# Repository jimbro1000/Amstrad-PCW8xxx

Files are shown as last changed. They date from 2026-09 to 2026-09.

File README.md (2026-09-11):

# Amstrad PCW8xxx Schematics #
This repository contains a KiCad project representing
the schematics of the main board of the Amstrad
PCW8256 and PCW8512 personal computers

The project is complete for schematics only

The PCB design holds accurate board dimensions and
mostly accurate component positions. Where a component
is a critical reference location this has been 
measured and placed as accurately as possible.

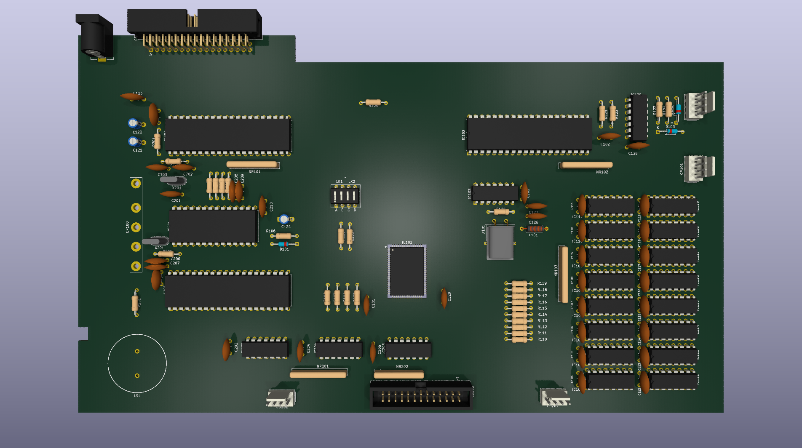
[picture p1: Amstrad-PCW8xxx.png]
render of PCB


# License #
This project is licensed under Creative Commons 4 BY-SA
See LICENSE file for full statement

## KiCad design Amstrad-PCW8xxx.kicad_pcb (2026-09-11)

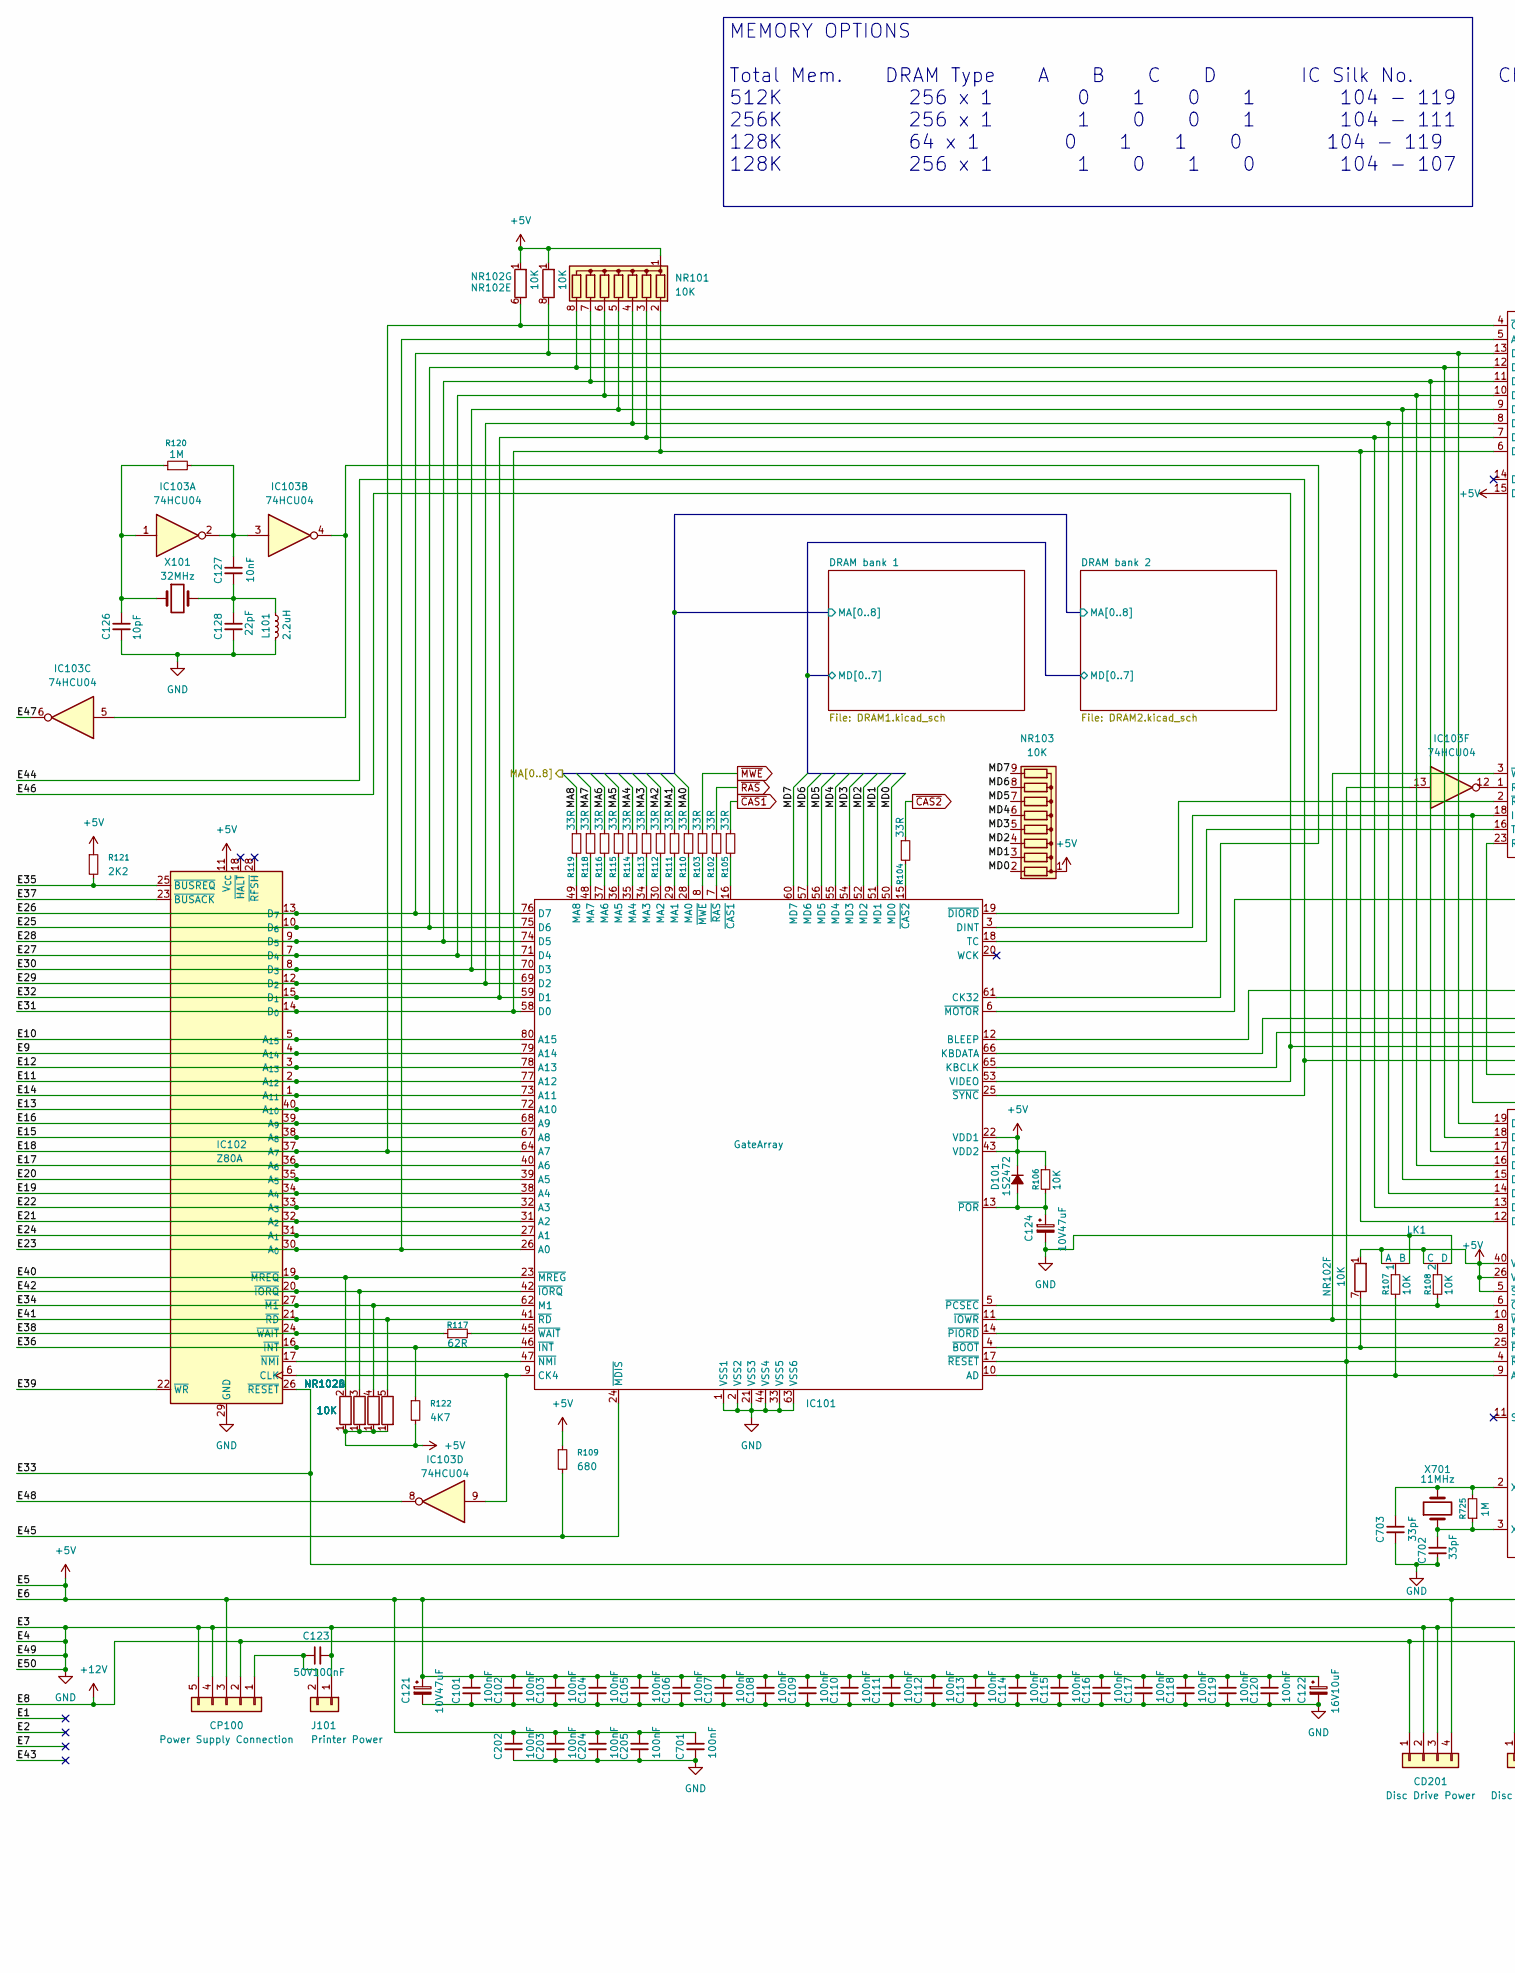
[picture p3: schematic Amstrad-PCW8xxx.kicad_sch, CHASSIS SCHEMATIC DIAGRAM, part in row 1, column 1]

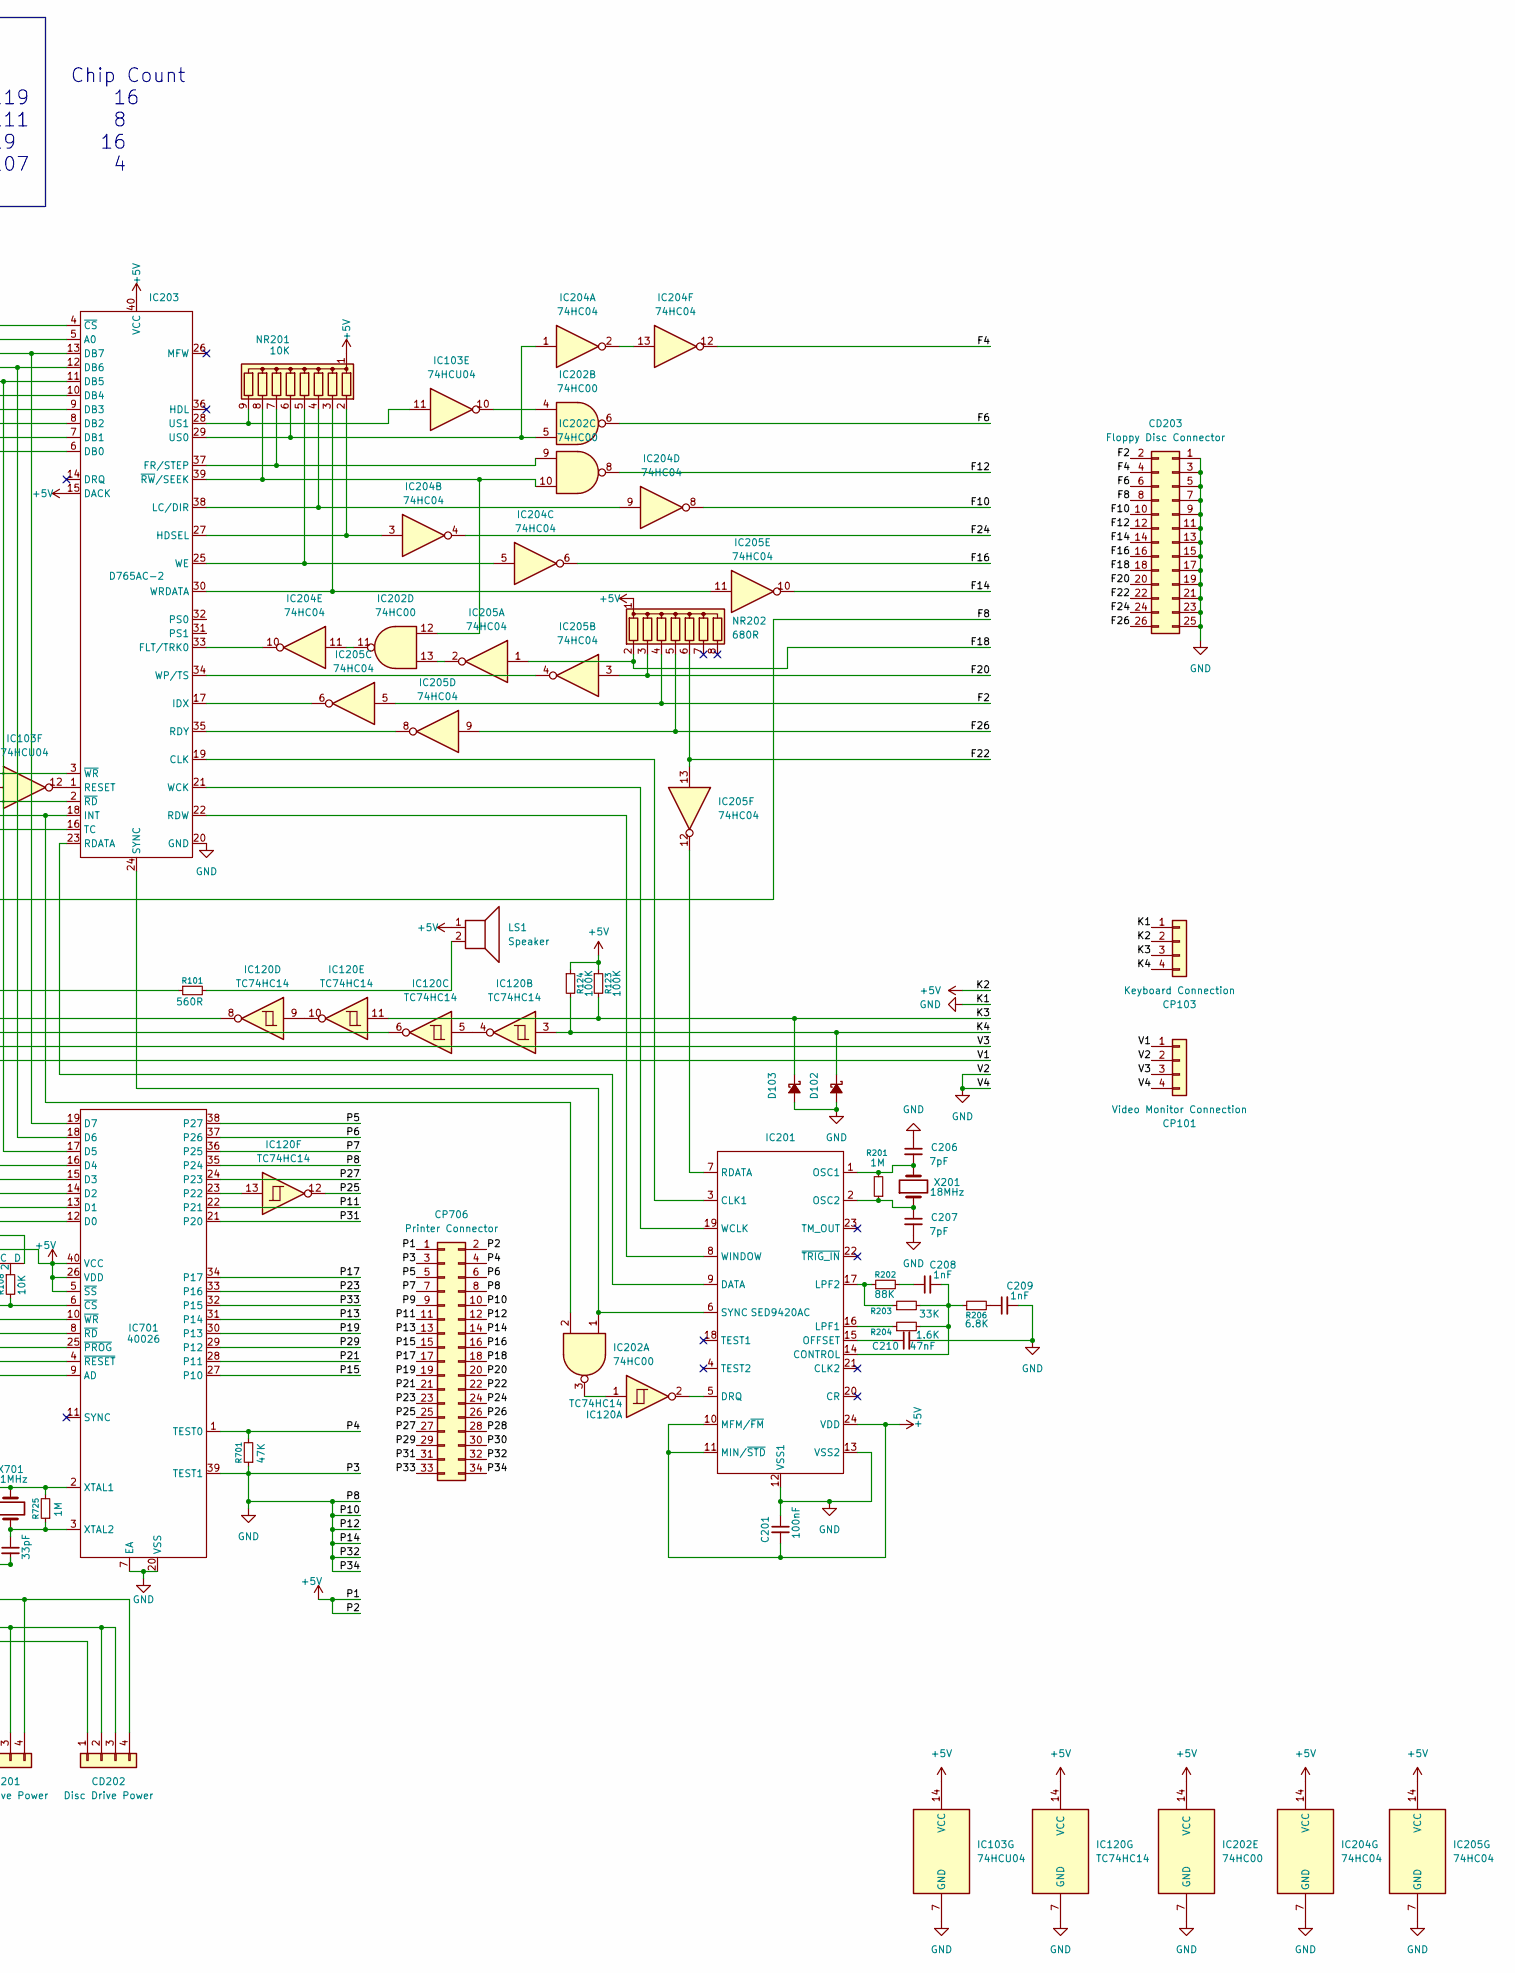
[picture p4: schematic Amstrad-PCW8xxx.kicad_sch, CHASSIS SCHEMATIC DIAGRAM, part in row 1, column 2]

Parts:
C101, C102, C103, C104, C105, C106, C107, C108, C109, C110, C111, C112, C113, C114, C115, C116, C117, C118, C119, C120, C201, C202, C203, C204, C205, C701: 100nF; C_Disc_D9.0mm_W2.5mm_P5.00mm
C121, C124: 10V47uF; CP_Radial_P5.00mm
C122: 16V10uF; CP_Radial_P5.00mm
C123: 50V100nF; C_Disc_D9.0mm_W2.5mm_P5.00mm
C126: 10pF; C_Disc_D9.0mm_W2.5mm_P5.00mm
C127: 10nF; C_Disc_D9.0mm_W2.5mm_P5.00mm
C128: 22pF; C_Disc_D9.0mm_W2.5mm_P5.00mm
C206, C207: 7pF; C_Disc_D9.0mm_W2.5mm_P5.00mm
C208, C209: 1nF; C_Disc_D9.0mm_W2.5mm_P5.00mm
C210: 47nF; C_Disc_D9.0mm_W2.5mm_P5.00mm
C702, C703: 33pF; C_Disc_D9.0mm_W2.5mm_P5.00mm
CD201, CD202: Disc Drive Power; Molex_KK-254_AE-6410-04A_1x04_P2.54mm_Vertical
CD203: Floppy Disc Connector; IDC-Header_2x13_P2.54mm_Vertical
CP100: Power Supply Connection; Power Connection
CP101: Video Monitor Connection; Molex_KK-254_AE-6410-04A_1x04_P2.54mm_Vertical
CP103: Keyboard Connection; Molex_KK-254_AE-6410-04A_1x04_P2.54mm_Vertical
CP706: Printer Connector; IDC-Header_2x17_P2.54mm_Horizontal
D101: 1S2472; D_DO-35_SOD27_P10.16mm_Horizontal
D102, D103: D_DO-35_SOD27_P10.16mm_Horizontal
IC101: GateArray; Amstrad_PQFP-80_14x20mm_P0.8mm
IC102: Z80A; DIP-40_W15.24mm
IC103: 74HCU04; DIP-14_W7.62mm
IC120: TC74HC14; DIP-14_W7.62mm
IC201: SED9420AC; DIP-28_W15.24mm
IC202: 74HC00; DIP-14_W7.62mm
IC203: D765AC-2; DIP-40_W15.24mm
IC204, IC205: 74HC04; DIP-14_W7.62mm
IC701: 40026; DIP-40_W15.24mm
J101: Printer Power; BarrelJack_Horizontal
L101: 2.2uH; L_Axial_L6.6mm_D2.7mm_P10.16mm_Horizontal_Vishay_IM-2
LK1: Link_2
LS1: Speaker
NR101, NR102: 10K; R_Array_SIP8
NR103, NR201: 10K; R_Array_SIP9
NR202: 680R; R_Array_SIP8
R101: 560R; R_Axial_DIN0207_L6.3mm_D2.5mm_P10.16mm_Horizontal
R102, R103, R104, R105, R110, R111, R112, R113, R114, R115, R116, R118, R119: 33R; R_Axial_DIN0207_L6.3mm_D2.5mm_P10.16mm_Horizontal
R106, R107, R108: 10K; R_Axial_DIN0207_L6.3mm_D2.5mm_P10.16mm_Horizontal
R109: 680; R_Axial_DIN0207_L6.3mm_D2.5mm_P10.16mm_Horizontal
R117: 62R; R_Axial_DIN0207_L6.3mm_D2.5mm_P10.16mm_Horizontal
R120, R201, R725: 1M; R_Axial_DIN0207_L6.3mm_D2.5mm_P10.16mm_Horizontal
R121: 2K2; R_Axial_DIN0207_L6.3mm_D2.5mm_P10.16mm_Horizontal
R122: 4K7; R_Axial_DIN0207_L6.3mm_D2.5mm_P10.16mm_Horizontal
R123, R124: 100K; R_Axial_DIN0207_L6.3mm_D2.5mm_P10.16mm_Horizontal
R202: 88K; R_Axial_DIN0207_L6.3mm_D2.5mm_P10.16mm_Horizontal
R203: 33K; R_Axial_DIN0207_L6.3mm_D2.5mm_P10.16mm_Horizontal
R204: 1.6K; R_Axial_DIN0207_L6.3mm_D2.5mm_P10.16mm_Horizontal
R206: 6.8K; R_Axial_DIN0207_L6.3mm_D2.5mm_P10.16mm_Horizontal
R701: 47K; R_Axial_DIN0207_L6.3mm_D2.5mm_P10.16mm_Horizontal
X101: 32MHz; Crystal_HC49-U_Horizontal_1EP_style2
X201: 18MHz; Crystal_HC52-8mm_Vertical
X701: 11MHz; Crystal_HC52-8mm_Vertical

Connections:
+5V: C101.1, C102.1, C103.1, C104.1, C105.1, C106.1, C107.1, C108.1, C109.1, C110.1, C111.1, C112.1, C113.1, C114.1, C115.1, C116.1, C117.1, C118.1, C119.1, C120.1, C121.1, C122.1, C201.2, C202.1, C203.1, C204.1, C205.1, C701.1, CD201.4, CD202.4, CP100.3, CP103.2, CP706.1, CP706.2, D101.1 (K), IC101.22 (VDD1), IC101.43 (VDD2), IC102.11 (V_{CC}), IC103.14 (VCC), IC120.14 (VCC), IC201.10 (MFM/~FM), IC201.11 (MIN/~STD), IC201.24 (VDD), IC202.14 (VCC), IC203.15 (DACK), IC203.40 (VCC), IC204.14 (VCC), IC205.14 (VCC), IC701.5 (~SS), IC701.26 (VDD), IC701.40 (VCC), LK1.A, LK1.C, LS1.1, NR101.1 (common), NR102.1 (R1), NR103.1 (common), NR201.1 (common), NR202.1 (common), R106.1, R109.1, R121.1, R122.2, R123.1, R124.1; also elsewhere on the board
+12V: CD201.1, CD202.1, CP100.2
/DRAM bank 1/MD0: IC101.50 (MD0), NR103.2 (R1); also elsewhere on the board
/DRAM bank 1/MD1: IC101.51 (MD1), NR103.3 (R2); also elsewhere on the board
/DRAM bank 1/MD2: IC101.52 (MD2), NR103.4 (R3); also elsewhere on the board
/DRAM bank 1/MD3: IC101.54 (MD3), NR103.5 (R4); also elsewhere on the board
/DRAM bank 1/MD4: IC101.55 (MD4), NR103.6 (R5); also elsewhere on the board
/DRAM bank 1/MD5: IC101.56 (MD5), NR103.7 (R6); also elsewhere on the board
/DRAM bank 1/MD6: IC101.57 (MD6), NR103.8 (R7); also elsewhere on the board
/DRAM bank 1/MD7: IC101.60 (MD7), NR103.9 (R8); also elsewhere on the board
/E9: IC101.79 (A14), IC102.4 (A_{14})
/E10: IC101.80 (A15), IC102.5 (A_{15})
/E11: IC101.77 (A12), IC102.2 (A_{12})
/E12: IC101.78 (A13), IC102.3 (A_{13})
/E13: IC101.72 (A10), IC102.40 (A_{10})
/E14: IC101.73 (A11), IC102.1 (A_{11})
/E15: IC101.67 (A8), IC102.38 (A_{8})
/E16: IC101.68 (A9), IC102.39 (A_{9})
/E17: IC101.40 (A6), IC102.36 (A_{6})
/E18: IC101.64 (A7), IC102.37 (A_{7}), IC203.4 (~CS), NR102.6 (R5.2)
/E19: IC101.38 (A4), IC102.34 (A_{4})
/E20: IC101.39 (A5), IC102.35 (A_{5})
/E21: IC101.31 (A2), IC102.32 (A_{2})
/E22: IC101.32 (A3), IC102.33 (A_{3})
/E23: IC101.26 (A0), IC102.30 (A_{0}), IC203.5 (A0)
/E24: IC101.27 (A1), IC102.31 (A_{1})
/E25: IC101.75 (D6), IC102.10 (D_{6}), IC203.12 (DB6), IC701.18 (D6), NR101.8 (R7)
/E26: IC101.76 (D7), IC102.13 (D_{7}), IC203.13 (DB7), IC701.19 (D7), NR102.8 (R7.2)
/E27: IC101.71 (D4), IC102.7 (D_{4}), IC203.10 (DB4), IC701.16 (D4), NR101.6 (R5)
/E28: IC101.74 (D5), IC102.9 (D_{5}), IC203.11 (DB5), IC701.17 (D5), NR101.7 (R6)
/E29: IC101.69 (D2), IC102.12 (D_{2}), IC203.8 (DB2), IC701.14 (D2), NR101.4 (R3)
/E30: IC101.70 (D3), IC102.8 (D_{3}), IC203.9 (DB3), IC701.15 (D3), NR101.5 (R4)
/E31: IC101.58 (D0), IC102.14 (D_{0}), IC203.6 (DB0), IC701.12 (D0), NR101.2 (R1)
/E32: IC101.59 (D1), IC102.15 (D_{1}), IC203.7 (DB1), IC701.13 (D1), NR101.3 (R2)
/E33: IC101.17 (~RESET), IC102.26 (~RESET), IC103.13, IC701.4 (~RESET)
/E34: IC101.62 (M1), IC102.27 (~M1), NR102.4 (R3.2)
/E35: IC102.25 (~BUSREQ), R121.2
/E36: IC101.46 (~INT), IC102.16 (~INT), R122.1
/E37: IC102.23 (~BUSACK)
/E38: IC102.24 (~WAIT), R117.1
/E39: IC102.22 (~WR)
/E40: IC101.23 (~MREG), IC102.19 (~MREQ), NR102.2 (R1.2)
/E41: IC101.41 (~RD), IC102.21 (~RD), NR102.5 (R4.2)
/E42: IC101.42 (~IORQ), IC102.20 (~IORQ), NR102.3 (R2.2)
/E44: CP101.1, IC101.25 (~SYNC)
/E45: IC101.24 (~MDIS), R109.2
/E46: CP101.3, IC101.53 (VIDEO)
/E47: IC103.6
/E48: IC103.8
/F2: CD203.2, IC205.5, NR202.4 (R3)
/F4: CD203.4, IC204.12
/F6: CD203.6, IC202.6
/F8: CD203.8, IC101.6 (~MOTOR)
/F10: CD203.10, IC204.8
/F12: CD203.12, IC202.8
/F14: CD203.14, IC205.10
/F16: CD203.16, IC204.6
/F18: CD203.18, IC205.1, NR202.2 (R1)
/F20: CD203.20, IC205.3, NR202.3 (R2)
/F22: CD203.22, IC205.13, NR202.6 (R5)
/F24: CD203.24, IC204.4
/F26: CD203.26, IC205.9, NR202.5 (R4)
/K3: CP103.3, D103.1 (K), IC120.11, R123.2
/K4: CP103.4, D102.1 (K), IC120.3, R124.2
/MA0: R110.1; also elsewhere on the board
/MA1: R111.1; also elsewhere on the board
/MA2: R112.1; also elsewhere on the board
/MA3: R113.1; also elsewhere on the board
/MA4: R114.1; also elsewhere on the board
/MA5: R115.1; also elsewhere on the board
/MA6: R116.1; also elsewhere on the board
/MA7: R118.1; also elsewhere on the board
/MA8: R119.1; also elsewhere on the board
/P4: CP706.4, IC701.1 (TEST0), R701.2
/P5: CP706.5, IC701.38 (P27)
/P6: CP706.6, IC701.37 (P26)
/P7: CP706.7, IC701.36 (P25)
/P9: CP706.9
/P11: CP706.11, IC701.22 (P21)
/P13: CP706.13, IC701.31 (P14)
/P15: CP706.15, IC701.27 (P10)
/P16: CP706.16
/P17: CP706.17, IC701.34 (P17)
/P18: CP706.18
/P19: CP706.19, IC701.30 (P13)
/P20: CP706.20
/P21: CP706.21, IC701.28 (P11)
/P22: CP706.22
/P23: CP706.23, IC701.33 (P16)
/P24: CP706.24
/P25: CP706.25, IC120.12
/P26: CP706.26
/P27: CP706.27, IC701.24 (P23)
/P28: CP706.28
/P29: CP706.29, IC701.29 (P12)
/P30: CP706.30
/P31: CP706.31, IC701.21 (P20)
/P33: CP706.33, IC701.32 (P15)
GND: C101.2, C102.2, C103.2, C104.2, C105.2, C106.2, C107.2, C108.2, C109.2, C110.2, C111.2, C112.2, C113.2, C114.2, C115.2, C116.2, C117.2, C118.2, C119.2, C120.2, C121.2, C122.2, C123.2, C124.2, C126.2, C128.2, C201.1, C202.2, C203.2, C204.2, C205.2, C206.1, C207.2, C209.2, C210.2, C701.2, C702.2, C703.2, CD201.2, CD201.3, CD202.2, CD202.3, CD203.1, CD203.3, CD203.5, CD203.7, CD203.9, CD203.11, CD203.13, CD203.15, CD203.17, CD203.19, CD203.21, CD203.23, CD203.25, CP100.4, CP100.5, CP101.2, CP101.4, CP103.1, CP706.3, CP706.8, CP706.10, CP706.12, CP706.14, CP706.32, CP706.34, D102.2 (A), D103.2 (A), IC101.1 (VSS1), IC101.2 (VSS2), IC101.21 (VSS3), IC101.33 (VSS5), IC101.44 (VSS4), IC101.63 (VSS6), IC102.29 (GND), IC103.7 (GND), IC120.7 (GND), IC201.12 (VSS1), IC201.13 (VSS2), IC202.7 (GND), IC203.20 (GND), IC204.7 (GND), IC205.7 (GND), IC701.7 (EA), IC701.20 (VSS), IC701.35 (P24), IC701.39 (TEST1), J101.1, L101.2, LK1.B, LK1.D, R701.1; also elsewhere on the board
unnamed: C126.1, IC103.1, R120.1, X101.1
unnamed: C127.1, IC103.2, IC103.3, R120.2
unnamed: C127.2, C128.1, L101.1, X101.2
unnamed: C208.1, R202.2
unnamed: C209.1, R206.2
unnamed: C123.1, CP100.1, J101.2
unnamed: C124.1, D101.2 (A), IC101.13 (~POR), R106.2
unnamed: IC101.10 (AD), IC701.9 (AD), R107.2
unnamed: IC101.12 (BLEEP), R101.1
unnamed: IC101.9 (CK4), IC102.6 (CLK), IC103.9
unnamed: IC101.61 (CK32), IC103.4, IC103.5
unnamed: IC101.3 (DINT), IC202.2, IC203.18 (INT)
unnamed: IC101.65 (KBCLK), IC120.6
unnamed: IC101.66 (KBDATA), IC120.8
unnamed: IC101.28 (MA0), R110.2
unnamed: IC101.29 (MA1), R111.2
unnamed: IC101.30 (MA2), R112.2
unnamed: IC101.34 (MA3), R113.2
unnamed: IC101.35 (MA4), R114.2
unnamed: IC101.36 (MA5), R115.2
unnamed: IC101.37 (MA6), R116.2
unnamed: IC101.48 (MA7), R118.2
unnamed: IC101.49 (MA8), R119.2
unnamed: IC101.18 (TC), IC203.16 (TC)
unnamed: IC101.4 (~BOOT), IC701.25 (~PROG), NR102.7 (R6.2)
unnamed: IC101.16 (~CAS1), R105.2
unnamed: IC101.15 (~CAS2), R104.2
unnamed: IC101.19 (~DIORD), IC203.2 (~RD)
unnamed: IC101.11 (~IOWR), IC203.3 (~WR), IC701.10 (~WR)
unnamed: IC101.8 (~MWE), R103.2
unnamed: IC101.47 (~NMI), IC102.17 (~NMI)
unnamed: IC101.5 (~PCSEC), IC701.6 (~CS), R108.2
unnamed: IC101.14 (~PIORD), IC701.8 (~RD)
unnamed: IC101.7 (~RAS), R102.2
unnamed: IC101.45 (~WAIT), R117.2
unnamed: IC103.10, IC202.4
unnamed: IC120.1, IC202.3
unnamed: IC120.4, IC120.5
unnamed: IC120.9, IC120.10
unnamed: IC201.3 (CLK1), IC203.19 (CLK)
unnamed: C208.2, IC201.14 (CONTROL), R203.2, R204.2, R206.1
unnamed: IC201.9 (DATA), IC203.23 (RDATA)
unnamed: IC120.2, IC201.5 (DRQ)
unnamed: IC201.16 (LPF1), R204.1
unnamed: IC201.17 (LPF2), R202.1, R203.1
unnamed: C210.1, IC201.15 (OFFSET)
unnamed: C206.2, IC201.1 (OSC1), R201.2, X201.2
unnamed: C207.1, IC201.2 (OSC2), R201.1, X201.1
unnamed: IC201.7 (RDATA), IC205.12
unnamed: IC201.6 (SYNC), IC202.1, IC203.24 (SYNC)
unnamed: IC201.19 (WCLK), IC203.21 (WCK)
unnamed: IC201.8 (WINDOW), IC203.22 (RDW)
unnamed: IC202.11, IC204.11
unnamed: IC202.13, IC205.2
unnamed: IC203.33 (FLT/TRK0), IC204.10
unnamed: IC202.9, IC203.37 (FR/STEP), NR201.7 (R6)
unnamed: IC203.27 (HDSEL), IC204.3, NR201.2 (R1)
unnamed: IC203.17 (IDX), IC205.6
unnamed: IC203.38 (LC/DIR), IC204.9, NR201.4 (R3)
unnamed: IC203.35 (RDY), IC205.8
unnamed: IC103.12, IC203.1 (RESET)
unnamed: IC202.5, IC203.29 (US0), IC204.1, NR201.6 (R5)
unnamed: IC103.11, IC203.28 (US1), NR201.9 (R8)
unnamed: IC203.25 (WE), IC204.5, NR201.5 (R4)
unnamed: IC203.34 (WP/TS), IC205.4
unnamed: IC203.30 (WRDATA), IC205.11, NR201.3 (R2)
unnamed: IC202.10, IC202.12, IC203.39 (~RW/SEEK), NR201.8 (R7)
unnamed: IC204.2, IC204.13
unnamed: IC120.13, IC701.23 (P22)
unnamed: C703.1, IC701.2 (XTAL1), R725.2, X701.2
unnamed: C702.1, IC701.3 (XTAL2), R725.1, X701.1
unnamed: LK1.1, R107.1
unnamed: LK1.2, R108.1
unnamed: LS1.2, R101.2
~CAS1: R105.1; also elsewhere on the board
~CAS2: R104.1; also elsewhere on the board
~MWE: R103.1; also elsewhere on the board
~RAS: R102.1; also elsewhere on the board

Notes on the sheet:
MEMORY OPTIONS Total Mem. DRAM Type A B C D IC Silk No. Chip Count 512K 256 x 1 0 1 0 1 104 - 119 16 256K 256 x 1 1 0 0 1 104 - 111 8 128K 64 x 1 0 1 1 0 104 - 119 16 128K 256 x 1 1 0 1 0 104 - 107 4

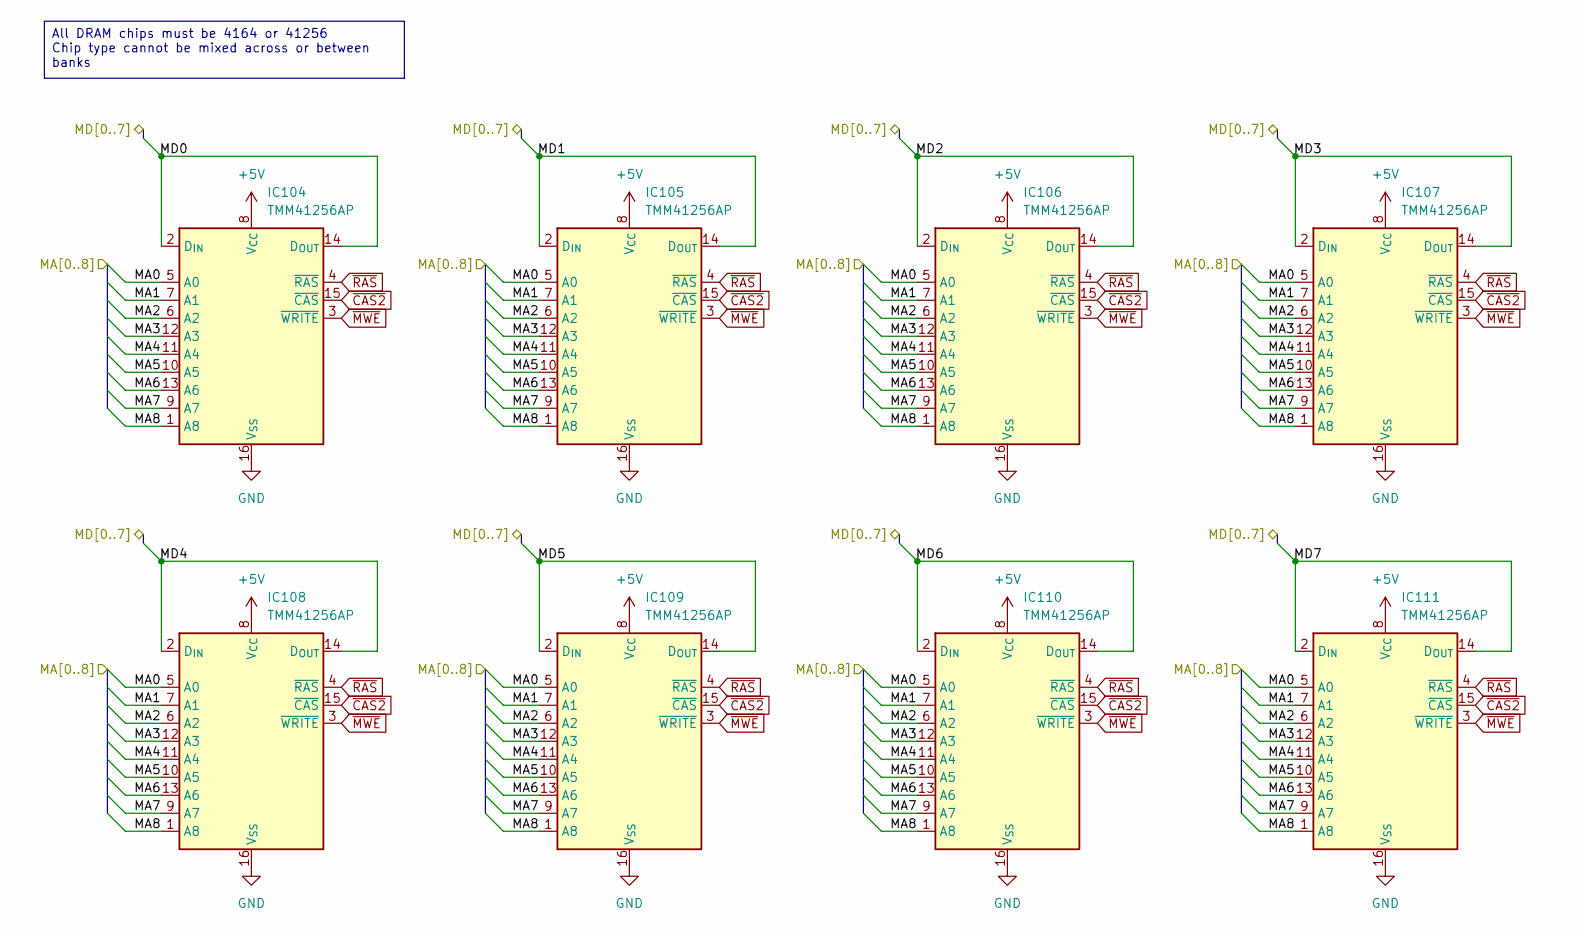
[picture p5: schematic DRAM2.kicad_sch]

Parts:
IC104, IC105, IC106, IC107, IC108, IC109, IC110, IC111: TMM41256AP; DIP-16_W7.62mm

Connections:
+5V: IC104.8 (V_{CC}), IC105.8 (V_{CC}), IC106.8 (V_{CC}), IC107.8 (V_{CC}), IC108.8 (V_{CC}), IC109.8 (V_{CC}), IC110.8 (V_{CC}), IC111.8 (V_{CC}); also elsewhere on the board
/DRAM bank 1/MD0: IC104.2 (D_{IN}), IC104.14 (D_{OUT}); also elsewhere on the board
/DRAM bank 1/MD1: IC105.2 (D_{IN}), IC105.14 (D_{OUT}); also elsewhere on the board
/DRAM bank 1/MD2: IC106.2 (D_{IN}), IC106.14 (D_{OUT}); also elsewhere on the board
/DRAM bank 1/MD3: IC107.2 (D_{IN}), IC107.14 (D_{OUT}); also elsewhere on the board
/DRAM bank 1/MD4: IC108.2 (D_{IN}), IC108.14 (D_{OUT}); also elsewhere on the board
/DRAM bank 1/MD5: IC109.2 (D_{IN}), IC109.14 (D_{OUT}); also elsewhere on the board
/DRAM bank 1/MD6: IC110.2 (D_{IN}), IC110.14 (D_{OUT}); also elsewhere on the board
/DRAM bank 1/MD7: IC111.2 (D_{IN}), IC111.14 (D_{OUT}); also elsewhere on the board
/MA0: IC104.5 (A0), IC105.5 (A0), IC106.5 (A0), IC107.5 (A0), IC108.5 (A0), IC109.5 (A0), IC110.5 (A0), IC111.5 (A0); also elsewhere on the board
/MA1: IC104.7 (A1), IC105.7 (A1), IC106.7 (A1), IC107.7 (A1), IC108.7 (A1), IC109.7 (A1), IC110.7 (A1), IC111.7 (A1); also elsewhere on the board
/MA2: IC104.6 (A2), IC105.6 (A2), IC106.6 (A2), IC107.6 (A2), IC108.6 (A2), IC109.6 (A2), IC110.6 (A2), IC111.6 (A2); also elsewhere on the board
/MA3: IC104.12 (A3), IC105.12 (A3), IC106.12 (A3), IC107.12 (A3), IC108.12 (A3), IC109.12 (A3), IC110.12 (A3), IC111.12 (A3); also elsewhere on the board
/MA4: IC104.11 (A4), IC105.11 (A4), IC106.11 (A4), IC107.11 (A4), IC108.11 (A4), IC109.11 (A4), IC110.11 (A4), IC111.11 (A4); also elsewhere on the board
/MA5: IC104.10 (A5), IC105.10 (A5), IC106.10 (A5), IC107.10 (A5), IC108.10 (A5), IC109.10 (A5), IC110.10 (A5), IC111.10 (A5); also elsewhere on the board
/MA6: IC104.13 (A6), IC105.13 (A6), IC106.13 (A6), IC107.13 (A6), IC108.13 (A6), IC109.13 (A6), IC110.13 (A6), IC111.13 (A6); also elsewhere on the board
/MA7: IC104.9 (A7), IC105.9 (A7), IC106.9 (A7), IC107.9 (A7), IC108.9 (A7), IC109.9 (A7), IC110.9 (A7), IC111.9 (A7); also elsewhere on the board
/MA8: IC104.1 (A8), IC105.1 (A8), IC106.1 (A8), IC107.1 (A8), IC108.1 (A8), IC109.1 (A8), IC110.1 (A8), IC111.1 (A8); also elsewhere on the board
GND: IC104.16 (V_{SS}), IC105.16 (V_{SS}), IC106.16 (V_{SS}), IC107.16 (V_{SS}), IC108.16 (V_{SS}), IC109.16 (V_{SS}), IC110.16 (V_{SS}), IC111.16 (V_{SS}); also elsewhere on the board
~CAS2: IC104.15 (~CAS), IC105.15 (~CAS), IC106.15 (~CAS), IC107.15 (~CAS), IC108.15 (~CAS), IC109.15 (~CAS), IC110.15 (~CAS), IC111.15 (~CAS); also elsewhere on the board
~MWE: IC104.3 (~WRITE), IC105.3 (~WRITE), IC106.3 (~WRITE), IC107.3 (~WRITE), IC108.3 (~WRITE), IC109.3 (~WRITE), IC110.3 (~WRITE), IC111.3 (~WRITE); also elsewhere on the board
~RAS: IC104.4 (~RAS), IC105.4 (~RAS), IC106.4 (~RAS), IC107.4 (~RAS), IC108.4 (~RAS), IC109.4 (~RAS), IC110.4 (~RAS), IC111.4 (~RAS); also elsewhere on the board

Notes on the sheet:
All DRAM chips must be 4164 or 41256 Chip type cannot be mixed across or between banks

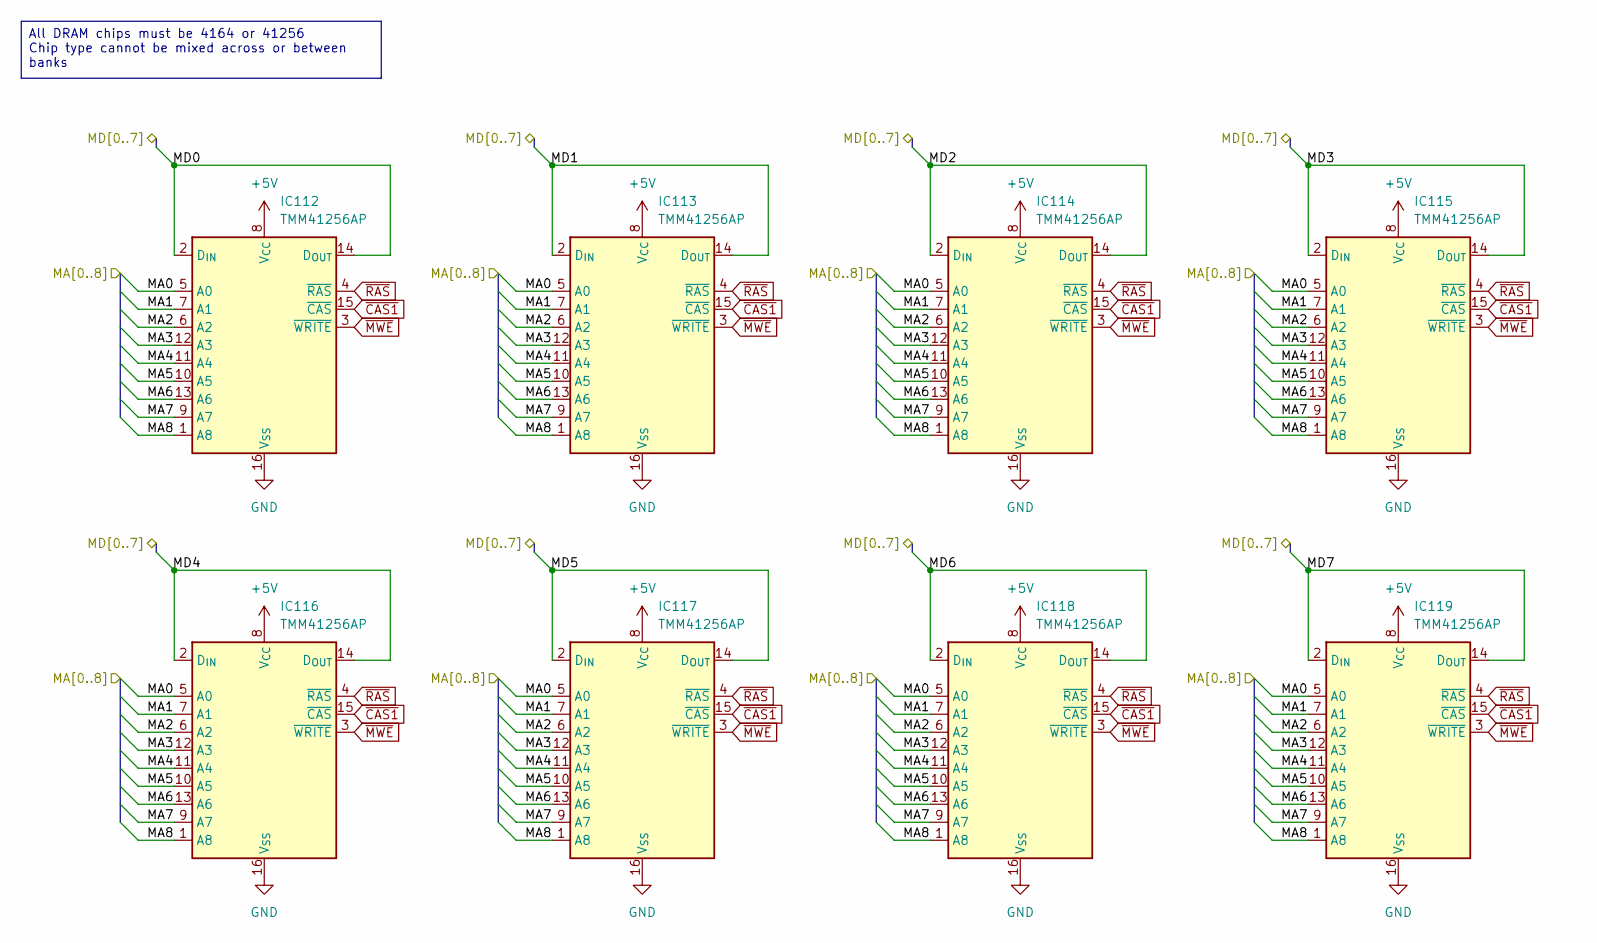
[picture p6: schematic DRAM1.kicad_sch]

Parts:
IC112, IC113, IC114, IC115, IC116, IC117, IC118, IC119: TMM41256AP; DIP-16_W7.62mm

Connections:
+5V: IC112.8 (V_{CC}), IC113.8 (V_{CC}), IC114.8 (V_{CC}), IC115.8 (V_{CC}), IC116.8 (V_{CC}), IC117.8 (V_{CC}), IC118.8 (V_{CC}), IC119.8 (V_{CC}); also elsewhere on the board
/DRAM bank 1/MD0: IC112.2 (D_{IN}), IC112.14 (D_{OUT}); also elsewhere on the board
/DRAM bank 1/MD1: IC113.2 (D_{IN}), IC113.14 (D_{OUT}); also elsewhere on the board
/DRAM bank 1/MD2: IC114.2 (D_{IN}), IC114.14 (D_{OUT}); also elsewhere on the board
/DRAM bank 1/MD3: IC115.2 (D_{IN}), IC115.14 (D_{OUT}); also elsewhere on the board
/DRAM bank 1/MD4: IC116.2 (D_{IN}), IC116.14 (D_{OUT}); also elsewhere on the board
/DRAM bank 1/MD5: IC117.2 (D_{IN}), IC117.14 (D_{OUT}); also elsewhere on the board
/DRAM bank 1/MD6: IC118.2 (D_{IN}), IC118.14 (D_{OUT}); also elsewhere on the board
/DRAM bank 1/MD7: IC119.2 (D_{IN}), IC119.14 (D_{OUT}); also elsewhere on the board
/MA0: IC112.5 (A0), IC113.5 (A0), IC114.5 (A0), IC115.5 (A0), IC116.5 (A0), IC117.5 (A0), IC118.5 (A0), IC119.5 (A0); also elsewhere on the board
/MA1: IC112.7 (A1), IC113.7 (A1), IC114.7 (A1), IC115.7 (A1), IC116.7 (A1), IC117.7 (A1), IC118.7 (A1), IC119.7 (A1); also elsewhere on the board
/MA2: IC112.6 (A2), IC113.6 (A2), IC114.6 (A2), IC115.6 (A2), IC116.6 (A2), IC117.6 (A2), IC118.6 (A2), IC119.6 (A2); also elsewhere on the board
/MA3: IC112.12 (A3), IC113.12 (A3), IC114.12 (A3), IC115.12 (A3), IC116.12 (A3), IC117.12 (A3), IC118.12 (A3), IC119.12 (A3); also elsewhere on the board
/MA4: IC112.11 (A4), IC113.11 (A4), IC114.11 (A4), IC115.11 (A4), IC116.11 (A4), IC117.11 (A4), IC118.11 (A4), IC119.11 (A4); also elsewhere on the board
/MA5: IC112.10 (A5), IC113.10 (A5), IC114.10 (A5), IC115.10 (A5), IC116.10 (A5), IC117.10 (A5), IC118.10 (A5), IC119.10 (A5); also elsewhere on the board
/MA6: IC112.13 (A6), IC113.13 (A6), IC114.13 (A6), IC115.13 (A6), IC116.13 (A6), IC117.13 (A6), IC118.13 (A6), IC119.13 (A6); also elsewhere on the board
/MA7: IC112.9 (A7), IC113.9 (A7), IC114.9 (A7), IC115.9 (A7), IC116.9 (A7), IC117.9 (A7), IC118.9 (A7), IC119.9 (A7); also elsewhere on the board
/MA8: IC112.1 (A8), IC113.1 (A8), IC114.1 (A8), IC115.1 (A8), IC116.1 (A8), IC117.1 (A8), IC118.1 (A8), IC119.1 (A8); also elsewhere on the board
GND: IC112.16 (V_{SS}), IC113.16 (V_{SS}), IC114.16 (V_{SS}), IC115.16 (V_{SS}), IC116.16 (V_{SS}), IC117.16 (V_{SS}), IC118.16 (V_{SS}), IC119.16 (V_{SS}); also elsewhere on the board
~CAS1: IC112.15 (~CAS), IC113.15 (~CAS), IC114.15 (~CAS), IC115.15 (~CAS), IC116.15 (~CAS), IC117.15 (~CAS), IC118.15 (~CAS), IC119.15 (~CAS); also elsewhere on the board
~MWE: IC112.3 (~WRITE), IC113.3 (~WRITE), IC114.3 (~WRITE), IC115.3 (~WRITE), IC116.3 (~WRITE), IC117.3 (~WRITE), IC118.3 (~WRITE), IC119.3 (~WRITE); also elsewhere on the board
~RAS: IC112.4 (~RAS), IC113.4 (~RAS), IC114.4 (~RAS), IC115.4 (~RAS), IC116.4 (~RAS), IC117.4 (~RAS), IC118.4 (~RAS), IC119.4 (~RAS); also elsewhere on the board

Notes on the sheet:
All DRAM chips must be 4164 or 41256 Chip type cannot be mixed across or between banks

Board: 2 copper layers, 119 parts (0 on the bottom side), 164 nets, no tracks yet.

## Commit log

2026-09-07 fix shared schematic across dram pages
    [Amstrad-PCW8xxx.kicad_sch, DRAM2.kicad_sch]
2026-09-08 fix incorrect gate array pin numbering
    [Amstrad-PCW8xxx.kicad_sch, DRAM1.kicad_sch]
2026-09-08 outline pcb
    [Amstrad-PCW8xxx.kicad_pcb, Amstrad-PCW8xxx.kicad_sch, DRAM1.kicad_sch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]
2026-09-09 progress PCB layout
    [Amstrad-PCW8xxx.kicad_pcb, Amstrad-PCW8xxx.kicad_sch]
2026-09-10 layout pcb components
    [Amstrad-PCW8xxx.kicad_pcb, Amstrad-PCW8xxx.kicad_sch]
2026-09-11 finish up PCB layout
    [Amstrad-PCW8xxx.kicad_pcb, Amstrad-PCW8xxx.kicad_sch]
